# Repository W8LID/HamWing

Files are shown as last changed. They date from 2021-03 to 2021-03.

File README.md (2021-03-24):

# HamWing
A FeatherWing for Dorji DRA818V/U modules that is compatible with Adafruit Feather system.

HamWing

The HamWing FeatherWing allows you to create a fully functional VHF/UHF transceiver using the Adafruit Feather platform. It has the same physical dimensions as the Feather Tripler making it easy to add a microcontroller as well as other FeatherWings like an OLED for a display. The modules are powered via the BAT pin to allow use with a LiPo pack connected to the Feather used for control. The HamWing was designed around the use of an Adafruit Feather M0 but should be compatible with other Feathers as well. We will list other compatible boards as they are verified to work.

The HamWIng can be built as a single band transceiver by populating only one RF module, low pass filter components and u.FL connector.

A 4 pin TRRS jack is used for a speaker mic with PTT button. A LM4810 amplifier is used for audio out. Mic input is shared with both modules. The PTT line is connected to a GPIO pin for use in keying the DRA818 module(s). Configuration of the modules is accomplished using AT commands via serial UART connected to each. The VHF module uses the default serail UART. The UHF module uses a second serial UART created using a SERCOM. This should also work on other Feathers using Software Serial.

Ouput of the modules is connected to a low pass filter to supress harmonics before being routed to a u.FL connector for each.

This project uses the following license for hardware, software and documentation.

hamwing_license

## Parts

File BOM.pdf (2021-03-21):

Sheet1

Referance | Value | Footprint | LCSC P/N | Digi-Key P/N
L1, L3 | 56nH | 0603 | C316308
L2 | 97nH (100nH) | 0603 | | 445-6386-1-ND
L4, L6 | 18nH | 0603 | C316321
L5 | 31nH (30nH) | 0603 | | 490-6883-1-ND
C1,2 | 27pF | 0603 | C342893
C3,4 | 8.7pF | 0603 | | 490-17287-1-ND
C5,6 | 0.47uF | 0603 | | 732-7912-1-ND
C7 | 1uF | 0603 | C26413
C8 | 4.7uF | 0805 | C215908
C9 | 100nF | 0603 | C42998
C10 | 100uF | 1206 | C77085
R1,2,3 | 20k | 0603 | C160027
R4,5 | 10k | 0603 | C269701
J1 | 1x16 Pin | 2.54mm
J2 | 1x12 Pin | 2.54mm
J3,4 | u.FL | | C88374
J5 | PJ320D
U1 | DRA818V
U2 | DRA818U
U3 | LM4810 | SSOP8 | | LM4810MM/NOPBCT-ND

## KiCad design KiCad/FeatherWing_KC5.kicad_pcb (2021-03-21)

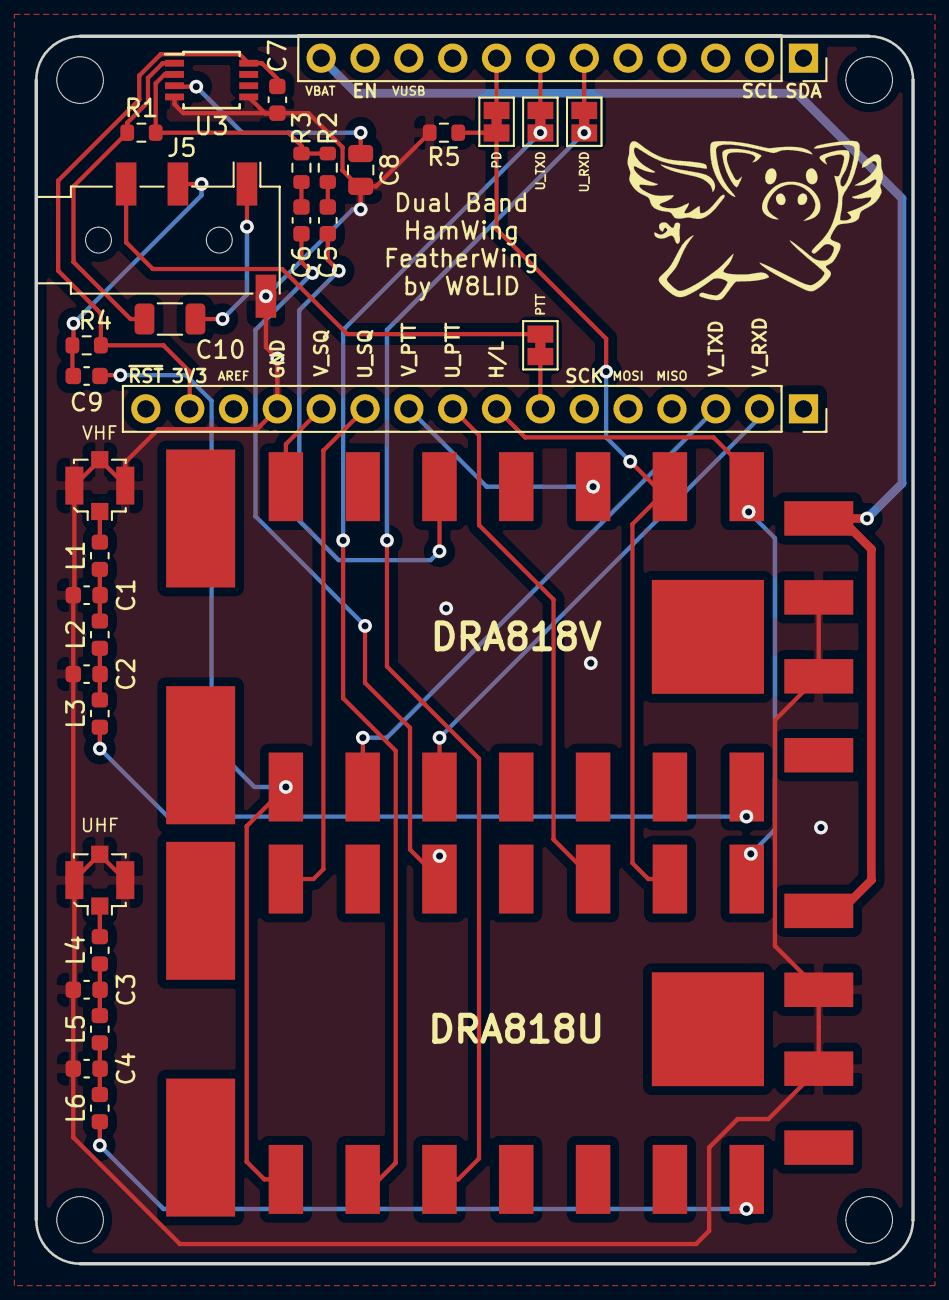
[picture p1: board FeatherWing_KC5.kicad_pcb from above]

Board: 2 copper layers, 50.8 x 71.1 mm, 33 parts (0 on the bottom side), 36 nets.

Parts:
C1, C2: 27pF; C_0603_1608Metric
C3, C4: 8.7pF; C_0603_1608Metric
C5, C6: 0.47uF; C_0603_1608Metric
C7: 1uF; C_0603_1608Metric
C8: 4.7uF; C_0805_2012Metric
C9: 100nF; C_0603_1608Metric
C10: 100uF; C_1206_3216Metric
J1: feather long; PinSocket_1x16_P2.54mm_Vertical
J2: feather short; PinSocket_1x12_P2.54mm_Vertical
J5: AudioJack4; Jack_3.5mm_PJ320D_Horizontal
JP1, JP2, JP3: Jumper_2_Bridged; SolderJumper-2_P1.3mm_Bridged_Pad1.0x1.5mm
L1, L3: 56nH; L_0603_1608Metric
L2: 100nH; L_0603_1608Metric
L4, L6: 18nH; L_0603_1608Metric
L5: 30nH; L_0603_1608Metric
PD: Jumper_2_Bridged; SolderJumper-2_P1.3mm_Bridged_Pad1.0x1.5mm
R1, R2, R3: 20k; R_0603_1608Metric
R4, R5: 10k; R_0603_1608Metric
U1: DRA818V; DRA818
U2: DRA818U; DRA818
U3: LM4810; TSSOP-8_3x3mm_P0.65mm
UHF: Conn_Coaxial; U.FL_Molex_MCRF_73412-0110_Vertical
VHF: Conn_Coaxial; U.FL_Molex_MCRF_73412-0110_Vertical

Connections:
+3V3: C7.2, J1.15, R4.2, U3.8
/A0: J1.12, U1.1
/A1: J1.11, U2.1
/A2: J1.10, U1.5
/A3: J1.9, U2.5
/A4: J1.8, U1.7, U2.7
/A5: J1.7, JP3.2
/F3: J2.6, JP2.1
/F4: J2.7, JP1.1
/F5: J2.8, PD.2
/RX: J1.3, U1.17
/TX: J1.2, U1.16
/VBAT: J2.12, U1.8, U2.8
GND: C1.2, C2.2, C3.2, C4.2, C7.1, C8.2, J1.13, J5.S, R5.1, U1.9, U1.10, U2.9, U2.10, U3.4, U3.5, UHF.2, VHF.2
unnamed: C1.1, L1.2, L2.1
unnamed: C2.1, L2.2, L3.1
unnamed: C3.1, L4.2, L5.1
unnamed: C4.1, L5.2, L6.1
unnamed: C5.1, U1.3
unnamed: C5.2, R2.1
unnamed: C6.1, U2.3
unnamed: C6.2, R3.2
unnamed: C8.1, U3.3
unnamed: C9.1, J5.R1, R4.1
unnamed: C9.2, U1.18, U2.18
unnamed: C10.1, J5.T
unnamed: C10.2, R1.1, U3.1
unnamed: L1.1, VHF.1
unnamed: L4.1, UHF.1
unnamed: J5.R2, JP3.1
unnamed: JP1.2, U2.17
unnamed: JP2.2, U2.16
unnamed: PD.1, R5.2, U1.6, U2.6
unnamed: L3.2, U1.12
unnamed: L6.2, U2.12
unnamed: R1.2, R2.2, R3.1, U3.2

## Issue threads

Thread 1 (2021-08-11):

Microcontroller audio/in out?

twopoint718, 2021-08-11:
This is an awesome project, thanks for all the work!

I was curious if it would make sense or be possible to route microcontroller pins to the audio in/out of the modules? My use case would be something like being able to send or receive APRS data. Thanks again.

-- Chris KD9KJV

W8LID, 2021-08-11:
Hey Chris,

Thanks for reaching out!

I have thought about this as well as having some pads available to do a crossover for in and out on the modules to give it cross band repeat capability. I need to do some research into what pin configuration would make the most sense and be compatible with as many feathers as possible.

If you have any recommendations please send them my way.

Best regards,

Mike Diehl
W8LID/VE6LID

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

twopoint718, 2021-08-12:
Will-do. I've worked a little with Cortex M0 in the past, but likewise I need to look at what the different feathers make available peripheral-wise. I'll be sure to let you know what I find out.
